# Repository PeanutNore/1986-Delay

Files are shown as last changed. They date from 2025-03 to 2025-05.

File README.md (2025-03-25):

# 1986-Delay
This program is distributed in the hope that it will be useful,
but WITHOUT ANY WARRANTY; without even the implied warranty of
MERCHANTABILITY or FITNESS FOR A PARTICULAR PURPOSE.

1986 Delay: A Stereo Digital Delay pedal for guitar built around the AVR128DA28 MCU.

Up to 1000 millisecond delay with stereo outputs and two modes

Mode 1: Ping-Pong delay. Output B has half the delay time of output A

Mode 2: "Reverse Ping-Pong" delay. Output A has half the selected delay time and runs like a stardard delay, while output B runs in reverse and is synchronized with output A for a stereo effect.

Digital Controls:

  A: Effective delay line length
  
  B: Sample rate

Analog Controls:

  Mix: The amount of delayed signal mixed with the dry signal at output
  
  Feedback: The amount of delayed signal mixed with the input signal to the delay line

 * Copyright 2025 Samuel Brown. All Rights Reservered.
 * 
 * Licensed under Creative Commons CC-BY-NC-SA 4.0
 * https://creativecommons.org/licenses/by-nc-sa/4.0/
 * 
 * You are free to share and adapt this software for non-
 * commercial purposes provided that you give appropriate 
 * credit and attribution, and distribute your contributions 
 * under the same CC-BY-NC-SA license.
 * 
 * For commercial licensing contact sam.brown.rit08@gmail.com

To use this software you will need:
* Arduino IDE version 1.8.19 or greater
* DxCore library for AVR128DA28 support (https://github.com/SpenceKonde/DxCore)
* Any USB to UPDI programmer. I recommend the Adafruit UPDI Friend because it is easy to use and under $20
* An AVR128DA28 MCU and appropriate supporting circuitry. Refer to the KiCad schematic and board files included in this repository.

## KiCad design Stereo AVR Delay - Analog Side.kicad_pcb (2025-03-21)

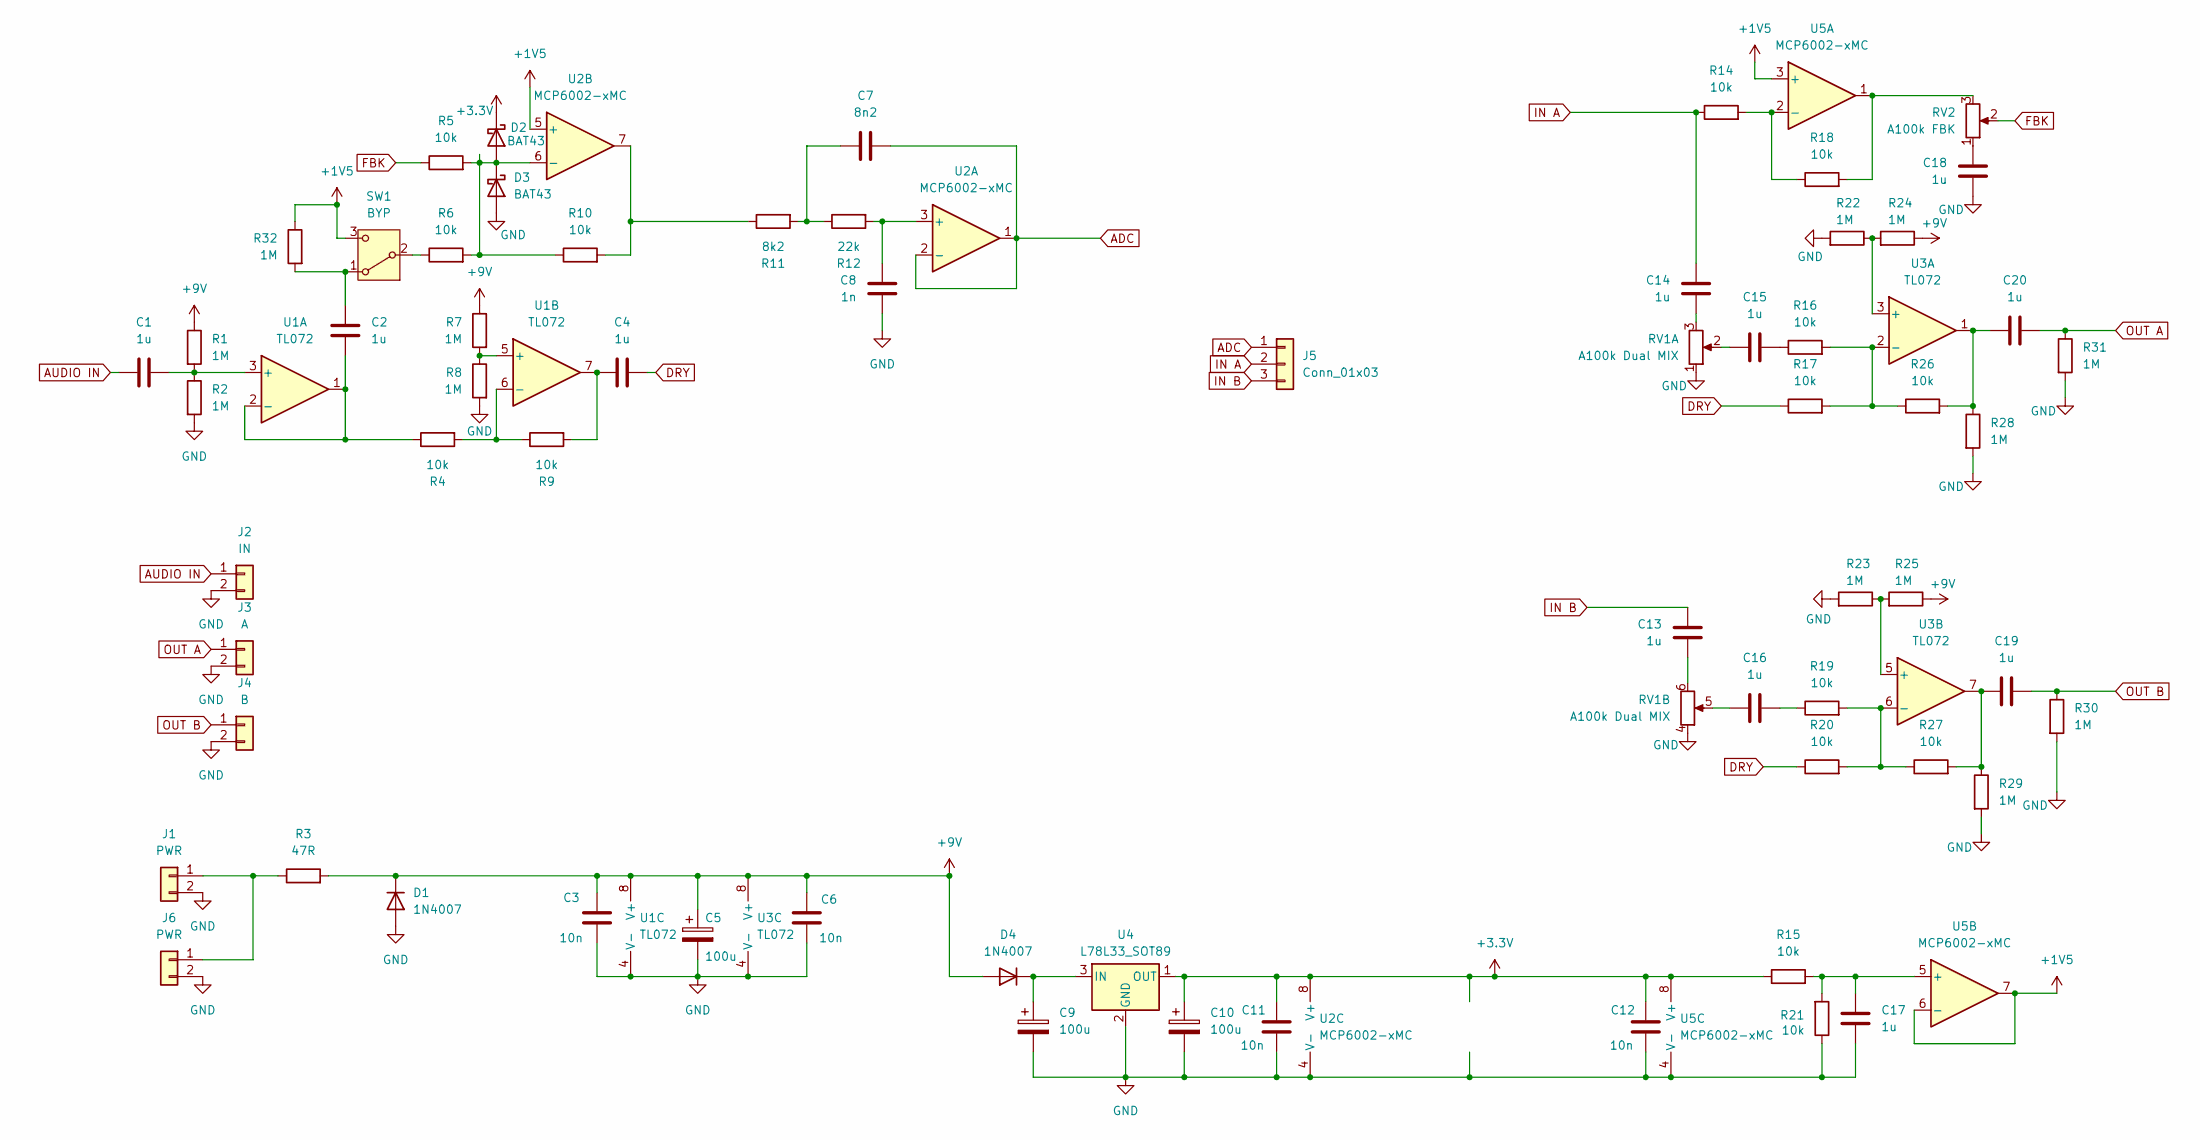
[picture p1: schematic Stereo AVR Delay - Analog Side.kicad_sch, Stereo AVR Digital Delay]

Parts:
C1, C2, C4, C13, C14, C15, C16, C17, C18, C19, C20: 1u; C_1206_3216Metric
C3, C6, C11, C12: 10n; C_0603_1608Metric
C5, C9, C10: 100u; CP_Radial_D6.3mm_P2.50mm
C7: 8n2; C_0603_1608Metric
C8: 1n; C_0603_1608Metric
D1, D4: 1N4007; D_DO-35_SOD27_P7.62mm_Horizontal
D2, D3: BAT43; D_DO-35_SOD27_P7.62mm_Horizontal
J1, J6: PWR; PinHeader_1x02_P2.54mm_Vertical
J2: IN; PinHeader_1x02_P2.54mm_Vertical
J3: A; PinHeader_1x02_P2.54mm_Vertical
J4: B; PinHeader_1x02_P2.54mm_Vertical
J5: Conn_01x03; PinHeader_1x03_P2.54mm_Vertical
R1, R2, R7, R8, R22, R23, R24, R25, R28, R29, R30, R31, R32: 1M; R_0805_2012Metric
R3: 47R; R_Axial_DIN0207_L6.3mm_D2.5mm_P7.62mm_Horizontal
R4, R5, R6, R9, R10, R14, R15, R16, R17, R18, R19, R20, R21, R26, R27: 10k; R_0805_2012Metric
R11: 8k2; R_0805_2012Metric
R12: 22k; R_0805_2012Metric
RV1: A100k Dual MIX; RV16A01F-41
RV2: A100k FBK; RV16AF-41
SW1: BYP; PinHeader_1x03_P2.54mm_Vertical
U1, U3: TL072; SOIC-8_3.9x4.9mm_P1.27mm
U2, U5: MCP6002-xMC; DIP-8_W7.62mm_Socket
U4: L78L33_SOT89; TO-92_Inline_Wide

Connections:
+1V5: R32.1, SW1.3 (C), U2.5 (+), U5.3 (+), U5.6 (-), U5.7
+3.3V: C10.1, C11.1, C12.1, D2.1 (K), R15.1, U2.8 (V+), U4.1 (OUT), U5.8 (V+)
+9V: C3.1, C5.1, C6.1, D1.1 (K), D4.2 (A), R1.1, R3.2, R7.1, R24.1, R25.1, U1.8 (V+), U3.8 (V+)
ADC: C7.2, J5.1, U2.1, U2.2 (-)
AUDIO IN: C1.1, J2.1
DRY: C4.2, R17.1, R20.1
FBK: R5.1, RV2.2
GND: C3.2, C5.2, C6.2, C8.1, C9.2, C10.2, C11.2, C12.2, C17.1, C18.1, D1.2 (A), D3.2 (A), J1.2, J2.2, J3.2, J4.2, J6.2, R2.2, R8.2, R21.1, R22.2, R23.2, R28.2, R29.2, R30.2, R31.2, RV1.1, RV1.4, U1.4 (V-), U2.4 (V-), U3.4 (V-), U4.2 (GND), U5.4 (V-)
IN A: C14.2, J5.2, R14.1
IN B: C13.2, J5.3
unnamed: C4.1, R9.2, U1.7
unnamed: C7.1, R11.2, R12.1
unnamed: C13.1, RV1.6
unnamed: C14.1, RV1.3
unnamed: C15.1, RV1.2
unnamed: C15.2, R16.1
unnamed: C16.1, RV1.5
unnamed: C16.2, R19.1
unnamed: C18.2, RV2.1
unnamed: C19.1, R27.2, R29.1, U3.7
unnamed: C20.1, R26.2, R28.1, U3.1
unnamed: D2.2 (A), D3.1 (K), R5.2, R6.2, R10.1, U2.6 (-)
unnamed: C9.1, D4.1 (K), U4.3 (IN)
unnamed: J1.1, J6.1, R3.1
unnamed: R10.2, R11.1, U2.7
unnamed: R18.2, RV2.3, U5.1
unnamed: C2.2, R32.2, SW1.1 (A)
unnamed: R6.1, SW1.2 (B)
unnamed: C1.2, R1.2, R2.1, U1.3 (+)
unnamed: C2.1, R4.1, U1.1, U1.2 (-)
unnamed: R7.2, R8.1, U1.5 (+)
unnamed: R4.2, R9.1, U1.6 (-)
unnamed: C8.2, R12.2, U2.3 (+)
unnamed: R22.1, R24.2, U3.3 (+)
unnamed: R16.2, R17.2, R26.1, U3.2 (-)
unnamed: R23.1, R25.2, U3.5 (+)
unnamed: R19.2, R20.2, R27.1, U3.6 (-)
unnamed: R14.2, R18.1, U5.2 (-)
unnamed: C17.2, R15.2, R21.2, U5.5 (+)
OUT A: C20.2, J3.1, R31.1
OUT B: C19.2, J4.1, R30.1

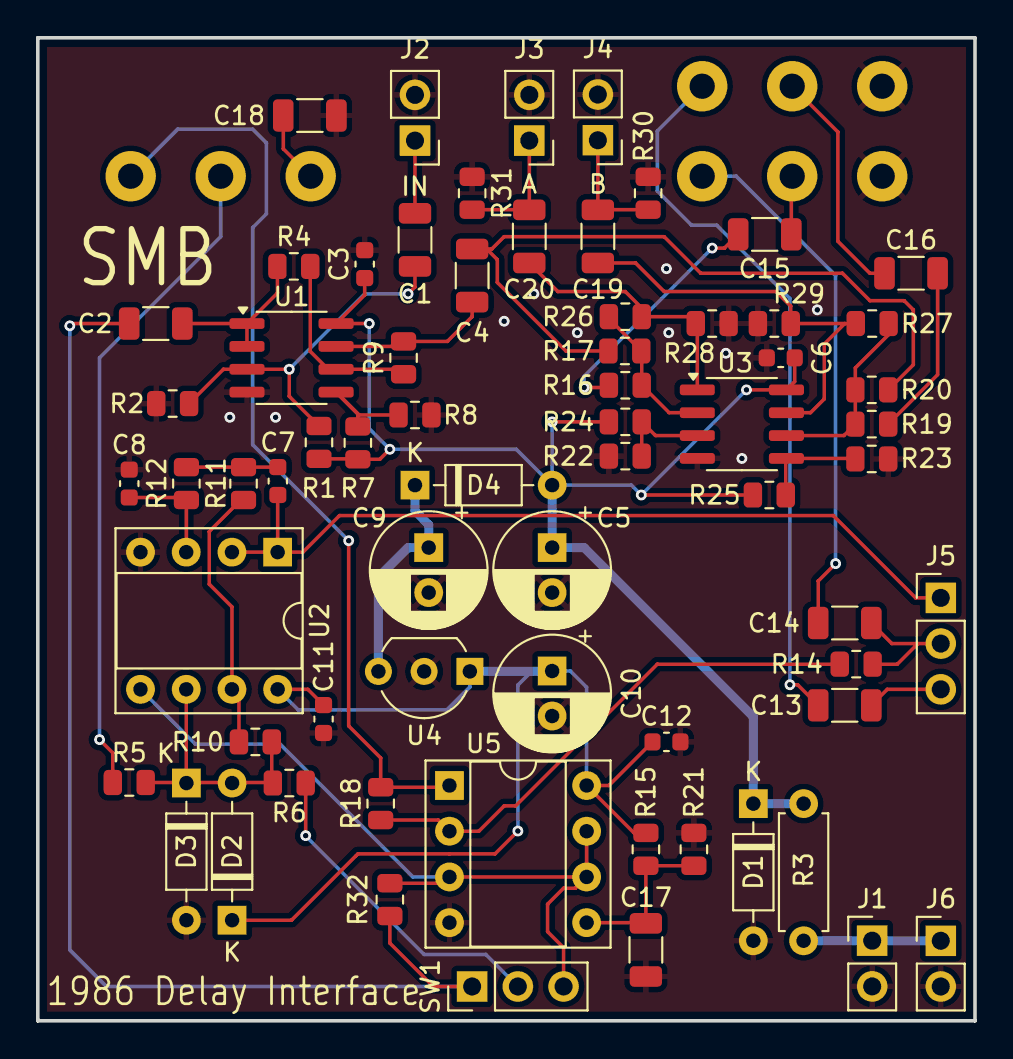
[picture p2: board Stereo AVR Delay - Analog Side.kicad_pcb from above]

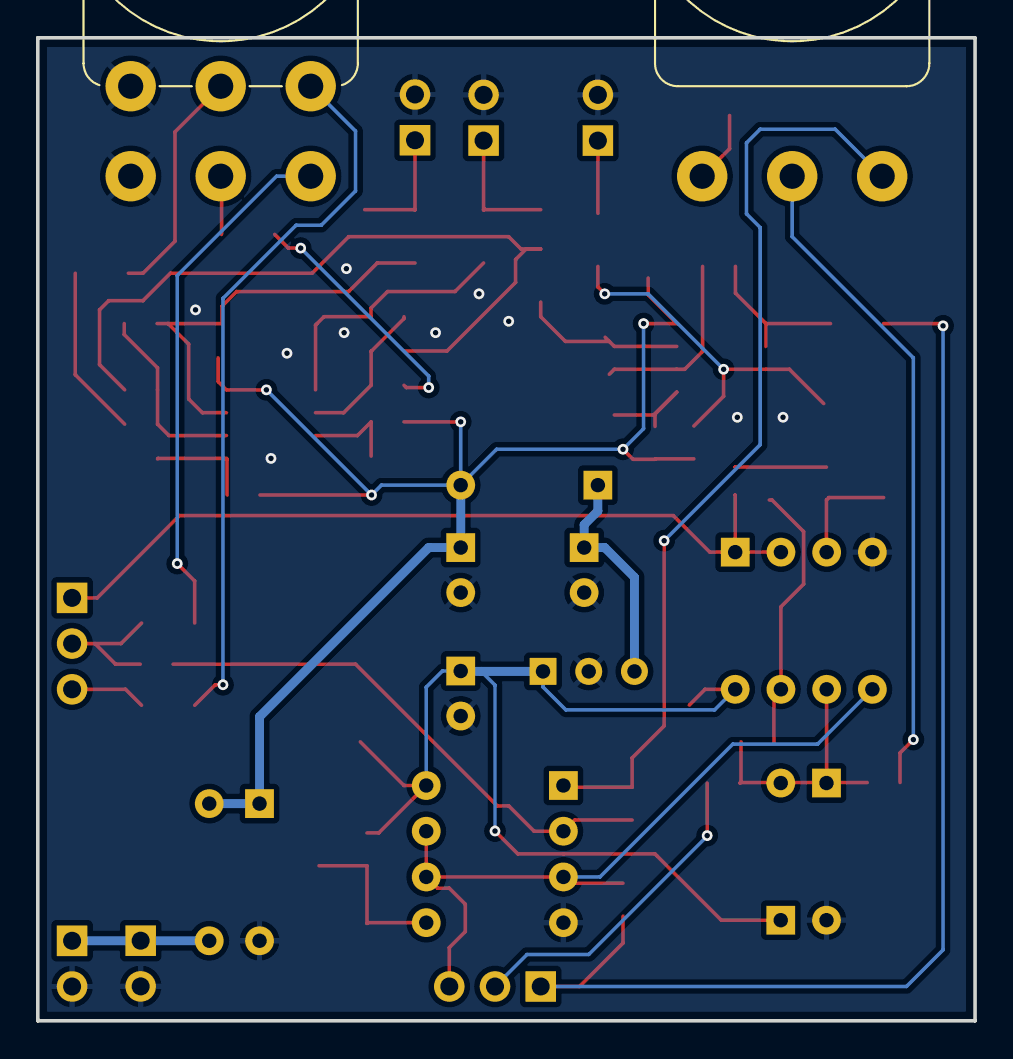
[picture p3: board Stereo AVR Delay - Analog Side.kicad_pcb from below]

Board: 2 copper layers, 52.1 x 54.6 mm, 69 parts (2 on the bottom side), 41 nets.

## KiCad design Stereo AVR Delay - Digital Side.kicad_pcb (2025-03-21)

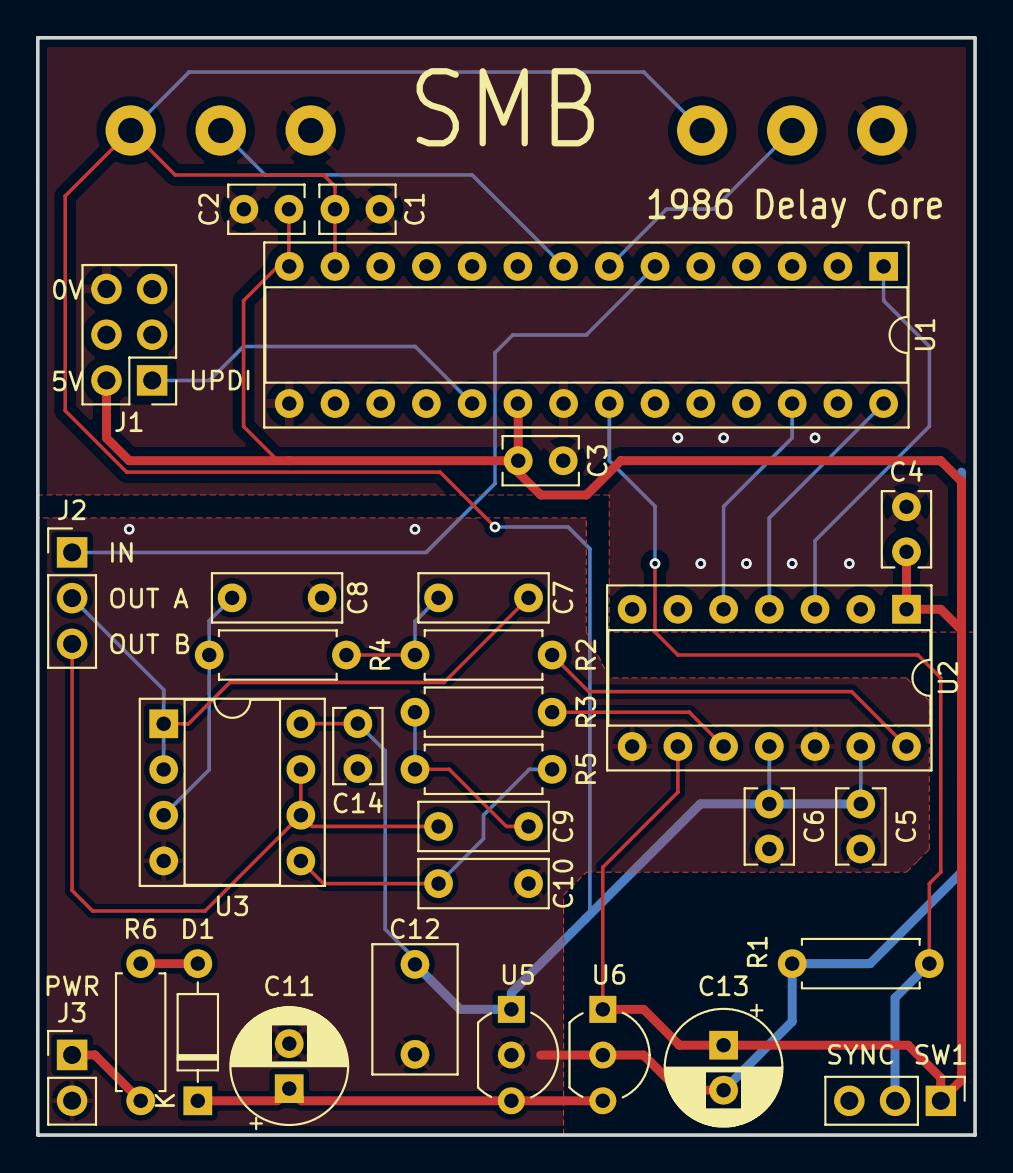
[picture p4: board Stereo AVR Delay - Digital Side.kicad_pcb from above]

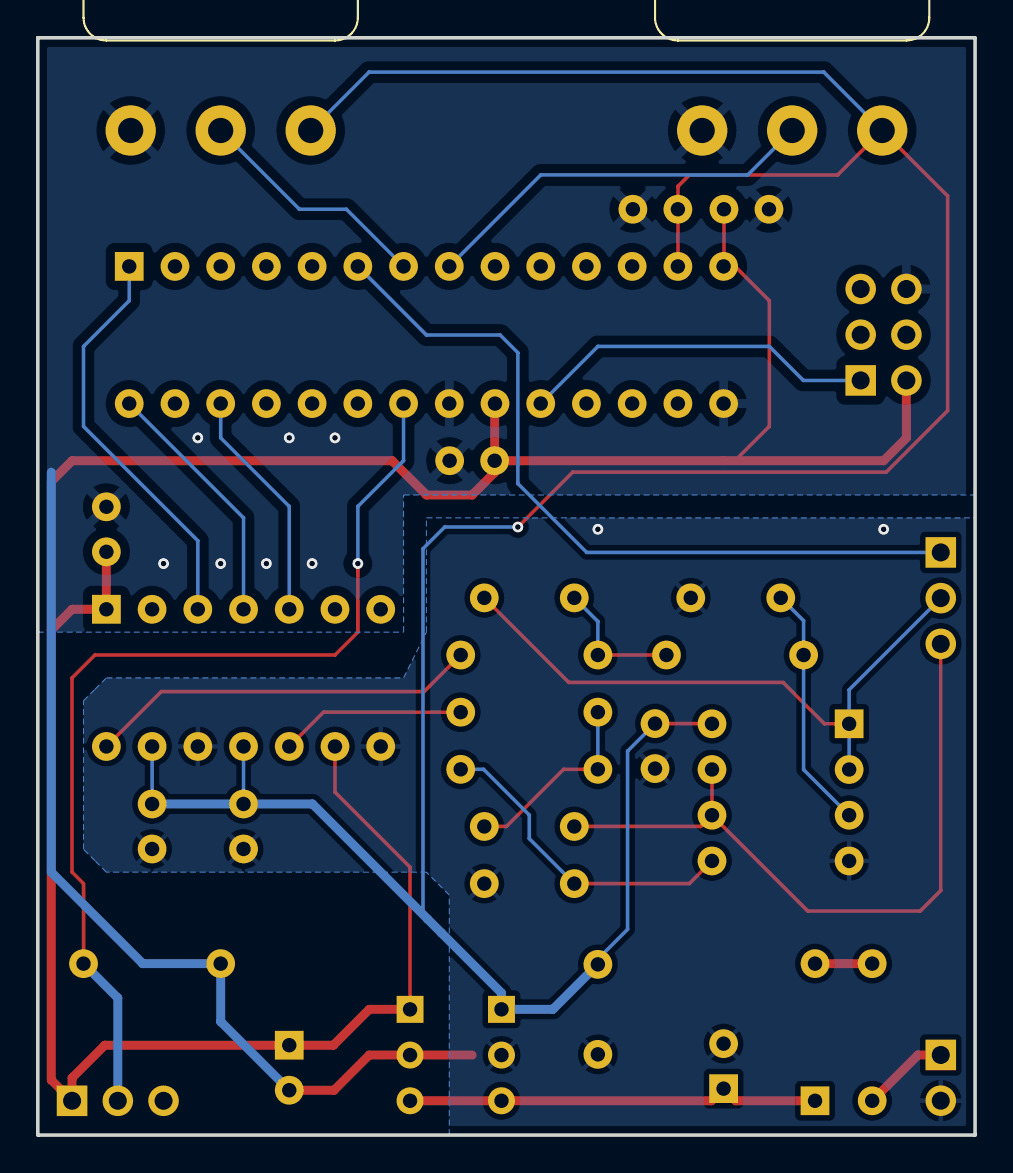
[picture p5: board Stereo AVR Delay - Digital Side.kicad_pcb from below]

Board: 2 copper layers, 52.1 x 61.0 mm, 32 parts (2 on the bottom side), 22 nets.

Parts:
C1, C2, C3, C4, C5, C6, C14: 10n; C_Rect_L4.0mm_W2.5mm_P2.50mm
C7, C9: 10n; C_Rect_L7.0mm_W2.5mm_P5.00mm
C8, C10: 1n2; C_Rect_L7.0mm_W2.5mm_P5.00mm
C11, C13: 100u; CP_Radial_D6.3mm_P2.50mm
C12: 1u; C_Rect_L7.0mm_W4.5mm_P5.00mm
D1: 1N4007; D_DO-35_SOD27_P7.62mm_Horizontal
J1: UPDI; PinHeader_2x03_P2.54mm_Vertical
J2: Conn_01x03; PinHeader_1x03_P2.54mm_Vertical
J3: PWR; PinHeader_1x02_P2.54mm_Vertical
R1, R4, R5: 22k; R_Axial_DIN0207_L6.3mm_D2.5mm_P7.62mm_Horizontal
R2, R3: 9k1; R_Axial_DIN0207_L6.3mm_D2.5mm_P7.62mm_Horizontal
R6: 47R; R_Axial_DIN0207_L6.3mm_D2.5mm_P7.62mm_Horizontal
RV1: 25k Delay Time A; RV16AF-41
RV2: 25k Delay Time B; RV16AF-41
SW1: SYNC; PinHeader_1x03_P2.54mm_Vertical
U1: AVR128DA28; DIP-28_W7.62mm_Socket
U2: MCP4922; DIP-14_W7.62mm_Socket
U3: MCP6002-xMC; DIP-8_W7.62mm_Socket
U5: L78L33; TO-92_Inline_Wide
U6: L78L05; TO-92_Inline_Wide

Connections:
+3.3V: C1.2, C5.1, C6.1, C12.1, C14.2, RV1.3, RV2.3, U1.13 (VREFA/PD7), U2.11 (VrefB), U2.13 (VrefA), U3.8 (V+), U5.1 (OUT)
+5V: C2.2, C3.1, C4.2, C13.1, J1.2 (VCC), SW1.1 (A), U1.14 (AVDD), U1.20 (VDD), U2.1 (VDD), U2.9 (~SHDN), U6.1 (OUT)
ADC IN: J2.1, U1.6 (PD0)
GND: C1.1, C2.1, C3.2, C4.1, C5.2, C6.2, C8.1, C10.1, C11.2, C12.2, C13.2, C14.1, J1.6 (GND), J3.2, R1.2, RV1.1, RV2.1, U1.15 (GND), U1.21 (GND), U2.8 (~LDAC), U2.12 (AVSS), U3.4 (V-), U5.2 (GND), U6.2 (GND)
unnamed: C7.1, R2.2, R4.1
unnamed: C9.1, R3.2, R5.1
unnamed: D1.2 (A), R6.2
unnamed: C11.1, D1.1 (K), U5.3 (IN), U6.3 (IN)
unnamed: J1.1 (DATA), U1.19 (UPDI)
unnamed: J3.1, R6.1
unnamed: R1.1, SW1.2 (B), U1.22 (PA0)
unnamed: U1.26 (PA4), U2.5 (SDI)
unnamed: U1.28 (PA6), U2.4 (SCK)
unnamed: U1.1 (PA7), U2.3 (~CS)
unnamed: RV1.2, U1.7 (PD1)
unnamed: RV2.2, U1.8 (PD2)
unnamed: R2.1, U2.14 (VoutA)
unnamed: R3.1, U2.10 (VoutB)
unnamed: C8.2, R4.2, U3.3 (+)
unnamed: C10.2, R5.2, U3.5 (+)
OUT A: C7.2, J2.2, U3.1, U3.2 (-)
OUT B: C9.2, J2.3, U3.6 (-), U3.7

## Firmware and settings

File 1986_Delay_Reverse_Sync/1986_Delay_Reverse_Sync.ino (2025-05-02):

/* 1986 Delay
 * Stereo Digital Delay Pedal for Guitar
 * High resolution version with half delay time - reads and stores full 12 bit samples in delay array
 * Version 1.2
 * 
 * Requries the following libraries:
 * DxCore - https://github.com/SpenceKonde/DxCore - install via Boards Manager in Arduino IDE
 * 
 * Removed requirement for MCP_DAC library - now calls SPI functions directly
 * 
 * For AVR512DA28 microcontrollers
 * 
 * Copyright 2025 Samuel Brown. All Rights Reservered.
 * 
 * Licensed under Creative Commons CC-BY-NC-SA 4.0
 * https://creativecommons.org/licenses/by-nc-sa/4.0/
 * 
 * You are free to share and adapt this software for non-
 * commercial purposes provided that you give appropriate 
 * credit and attribution, and distribute your contributions 
 * under the same CC-BY-NC-SA license.
 * 
 * For commercial licensing contact sam.brown.rit08@gmail.com
 */

#include "SPI.h"


//IO Pins
const uint8_t InputPin = PIN_PD0;
const uint8_t TimePinA = PIN_PD1;
const uint8_t TimePinB = PIN_PD2;
const uint8_t SyncPin = PIN_PA0;
const uint8_t DAC_CS = PIN_PA7;
//Audio Samples
volatile uint16_t sampleIn;
volatile uint16_t sampleOutA;
volatile uint16_t sampleOutB;
volatile uint16_t delayArray[8000];
//Step Counters
volatile uint16_t sampleStep = 0;
volatile int16_t delayStepA = 0;
volatile int16_t delayStepB = 0;
//Controls
volatile uint16_t delayTimeA = 0;
volatile uint16_t targetTimeA = 0;
volatile uint16_t delayTimeB = 0;
volatile uint16_t targetTimeB = 0;
volatile uint16_t extraClocks = 0;
volatile bool resetSample = false;

uint32_t _SPIspeed = 20000000;
SPISettings _spi_settings;

ISR(TCA0_OVF_vect) {                                        //runs each time the TCA0 periodic interrupt triggers
  TCA0.SINGLE.INTFLAGS = TCA_SINGLE_OVF_bm;                 //clear the interrupt flags

  //analogSampleDuration(0);
  sampleIn = analogRead(InputPin);                          //read the audio input
  //ADC0.MUXPOS = ((TimePinA & 0x7F) << ADC_MUXPOS_gp);
  
  //analogSampleDuration(4);
  targetTimeA = analogRead(TimePinA) >> 3;                   //read the delay time A knob as a value from 0-511 to reduce noise
  targetTimeA *= 15;                                         //scale it to 0-7665
  targetTimeA += 335;                                        //shift it so it maxes out at 8000
  if (delayTimeA < targetTimeA){delayTimeA++;}
  if (delayTimeA > targetTimeA){delayTimeA--;}
  delayTimeB = delayTimeA >> 1;                             //set delay time B to half of delay time 

  extraClocks = analogRead(TimePinB) >> 1;
  TCA0.SINGLE.PERBUF = 1200 + extraClocks;

  //reverse ping pong mode
  if (digitalReadFast(SyncPin)){
    delayStepA = sampleStep - delayTimeB;
    if (delayStepA < 0){delayStepA += delayTimeA;}
    delayStepB--;
    if (delayStepB < 0){delayStepB = delayTimeA;}
    if (sampleStep == (delayTimeA - 1)){resetSample = true;}
  }

  //default mode: ping pong
  else {
    delayStepA = sampleStep - delayTimeA;
    if (delayStepA < 0){delayStepA += 8000;}
    delayStepB = sampleStep - delayTimeB;
    if (delayStepB < 0){delayStepB += 8000;}
  }

  ADC0.MUXPOS = ((InputPin & 0x7F) << ADC_MUXPOS_gp);
  
  //output the delayed samples via external DAC
  //prepare and output A:
  sampleOutA = delayArray[delayStepA];        //get the sample at step A
  sampleOutA |= 0x3000;                       //add the command bits for the DAC (channel 0)
  digitalWriteFast(DAC_CS, LOW);
  SPI.beginTransaction(_spi_settings);
  SPI.transfer((uint8_t)(sampleOutA >> 8));   //send the high byte first
  SPI.transfer((uint8_t)(sampleOutA & 0xFF)); //send the low byte second
  SPI.endTransaction();
  digitalWriteFast(DAC_CS, HIGH);
  //prepare and output B:
  sampleOutB = delayArray[delayStepB];        //get the sample at step B
  sampleOutB |= 0xB000;                       //add the command bits for the DAC (channel 1)
  digitalWriteFast(DAC_CS, LOW);
  SPI.beginTransaction(_spi_settings);
  SPI.transfer((uint8_t)(sampleOutB >> 8));   //send the high byte first
  SPI.transfer((uint8_t)(sampleOutB & 0xFF)); //send the low byte second
  SPI.endTransaction();
  digitalWriteFast(DAC_CS, HIGH);
  
  //re-read the input and average it with earlier reading and store it
  //analogSampleDuration(0);
  sampleIn += analogRead(InputPin);                         //read the audio input again and add it to the previous
  sampleIn = sampleIn >> 1;                                 //divide by 2 to get the average (reduce quantization noise)
  delayArray[sampleStep] = sampleIn;                        //store the input in the delay line
  
  //increment the step counter and roll over to 0 after the last position
  sampleStep++;
  if ((sampleStep > 7999) || resetSample){
    sampleStep = 0;
    delayStepB = delayTimeA;           //the record and reverse playback heads need to be rolled over together for this to work right
    resetSample = false;
  }
}

void setup() {
  //fill the delay array with silence
  for (int i = 0; i < 8000; i++){
    delayArray[i] = 2047;
  }
  //setup I/O
  SPI.begin();
  pinMode(InputPin, INPUT);
  pinMode(TimePinA, INPUT);
  pinMode(TimePinB, INPUT);
  pinMode(SyncPin, INPUT);
  pinMode(DAC_CS, OUTPUT);
  digitalWriteFast(DAC_CS, HIGH);
  _spi_settings = SPISettings(_SPIspeed, MSBFIRST, SPI_MODE0);
  //setup ADC
  analogReference(EXTERNAL);
  analogReadResolution(12);
  analogSampleDuration(0);
  analogClockSpeed(2000);
  //get starting control settings
  delayTimeA = analogRead(TimePinA) << 1;                   //read the delay time A knob as a value from 0-8191
  delayTimeA++;
  if (delayTimeA > 8000){delayTimeA = 8000;}
  delayTimeB = delayTimeA >> 1;                           //set delay time B to half of delay time 
  delayStepB = delayTimeA - 1;
  ADC0.MUXPOS = ((InputPin & 0x7F) << ADC_MUXPOS_gp);
  //setup interrupt timing for desired sample rate
  takeOverTCA0();
  TCA0.SINGLE.INTFLAGS = TCA_SINGLE_OVF_bm;
  TCA0.SINGLE.INTCTRL  = 0b00000001;                // overflow interrupt every PER cycles
  TCA0.SINGLE.CTRLA    = TCA_SINGLE_CLKSEL_DIV1_gc; // Clock prescaler / 1 (24 MHz)    
  TCA0.SINGLE.PER      = 1200;                      // ADJUST SAMPLE RATE HERE - 1000 clocks = 24ksps , 1200 clocks = 20ksps, 1500 clocks = 16ksps - ADJUST SAMPLE RATE HERE
  TCA0.SINGLE.CTRLA   |= 1;                         // Enables the timer
}

void loop() {
  // put your main code here, to run repeatedly:

}

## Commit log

2025-03-21 Added KiCad files
    [Stereo AVR Delay - Analog Side.kicad_pcb, Stereo AVR Delay - Analog Side.kicad_sch, Stereo AVR Delay - Digital Side.kicad_pcb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]
2025-03-24 Optimizations for higher sample rate
2025-03-25 Fixed typo in comments
    [1986_Delay_Reverse_Sync.ino]
